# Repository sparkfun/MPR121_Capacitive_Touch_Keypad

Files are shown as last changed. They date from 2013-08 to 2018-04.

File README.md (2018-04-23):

**NOTE:** *This product has been retired from our catalog. If you are looking for more up-to-date info, please check out some of these resources to see how other users are still hacking and improving on this product.*
* *[SparkFun Forum](https://forum.sparkfun.com/)*
* *[Comments Here on GitHub](https://github.com/sparkfun/MPR121_Capacitive_Touch_Keypad/issues)*
* *[IRC Channel](https://www.sparkfun.com/news/263)*

MPR121 Capacitive Touch Keypad
==============================

Capacitive Touch Keypad

[MPR121 Capacitive Touch Keypad (SEN-12017)](https://www.sparkfun.com/products/12017)

The MPR121 capacitive keypad uses the MPR121 and 12 touch sensitive pads to give you a simple 'keypad' with an I2C output. The board 
also has four mounting holes allowing it to be used as na input system in place of traditional buttons. 

Note: This is uses 3.3V logic. You will want to use a logic level converter with this for 5V systems. 

Repository Contents
-------------------
* **/Firmware** - Any firmware that the part ships with, 
* **/Hardware** - All Eagle design files (.brd, .sch)
* **/Production** - Test bed files and production panel files

Documentation
--------------
* **[Hookup Guide](https://learn.sparkfun.com/tutorials/mpr121-hookup-guide)** - Basic hookup guide for the MPR121.

Version History
---------------
* [SEN-10250](https://www.sparkfun.com/products/10250) Version 1.3

License Information
-------------------
The hardware is released under [Creative Commons Share-alike 3.0](http://creativecommons.org/licenses/by-sa/3.0/).  
All other code is open source so please feel free to do anything you want with it; you buy me a beer if you use this and we meet someday ([Beerware license](http://en.wikipedia.org/wiki/Beerware)).

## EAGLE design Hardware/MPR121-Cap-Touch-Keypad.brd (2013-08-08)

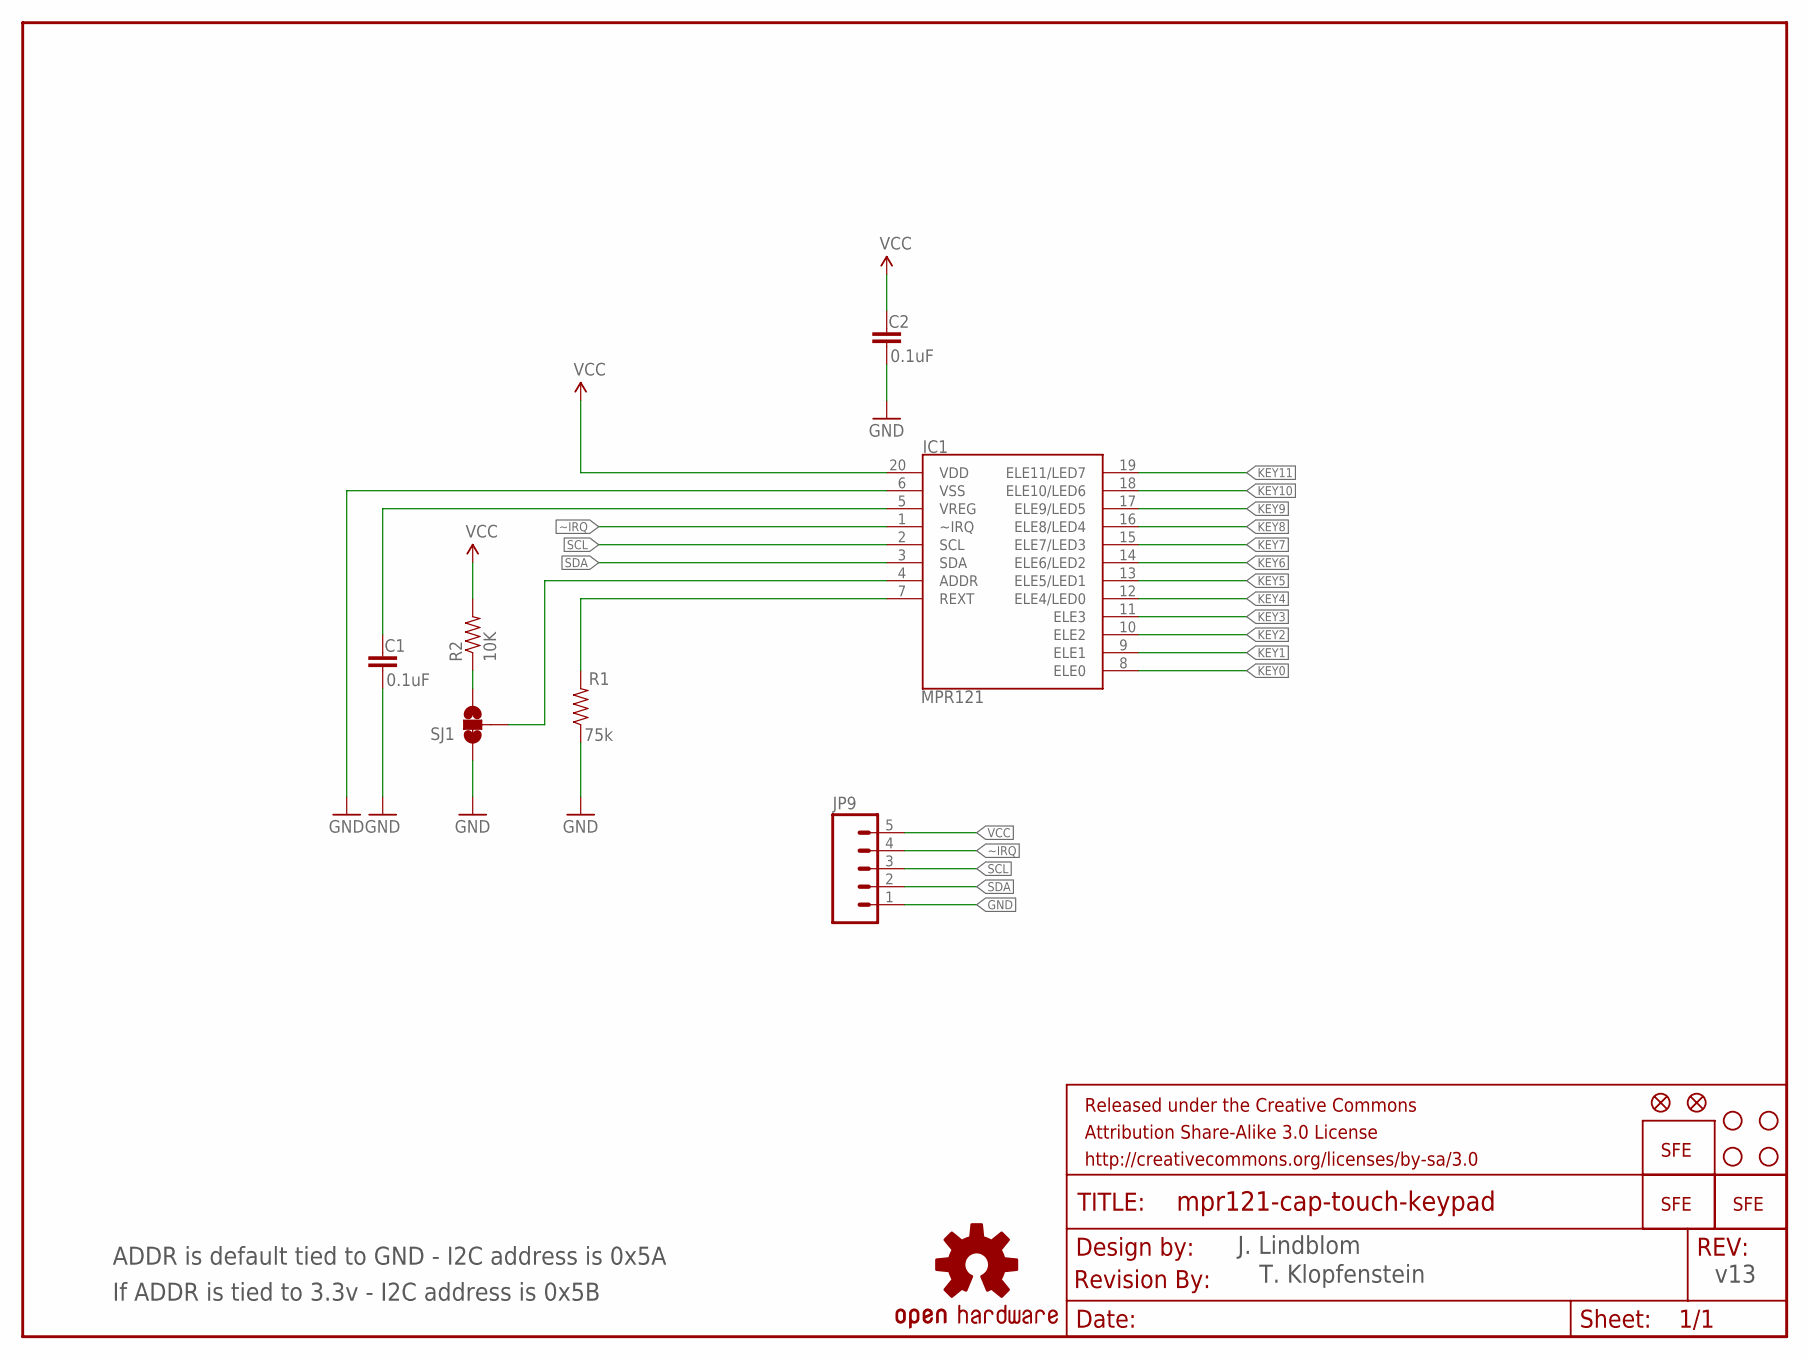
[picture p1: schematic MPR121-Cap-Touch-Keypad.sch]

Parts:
C1, C2: 0.1uF; 0603-CAP
FRAME1: FRAME-LETTER; CREATIVE_COMMONS
IC1: MPR121; QFN-20-0.4MM-V2
JP1: LOGO-SFENEW; SFE-NEW-WEBLOGO
JP2, JP6: LOGO-SFESK; SFE-LOGO-FLAME
JP3, JP4, JP7, JP8: STAND-OFF
JP5, JP10: FIDUCIAL1X2; FIDUCIAL-1X2
JP9: M05PTH; 1X05
LOGO1: OSHW-LOGOL; OSHW-LOGO-L
R1: 75k; 0603-RES
R2: 10K; 0603-RES
SJ1: SOLDERJUMPER_2WAYPASTE1&2; SJ_3_PASTE1&2
U$1: REVISION

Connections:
GND: C1.2, C2.2, IC1.6 (VSS), JP9.1, R1.1, SJ1.1
KEY0: IC1.8 (ELE0)
KEY1: IC1.9 (ELE1)
KEY2: IC1.10 (ELE2)
KEY3: IC1.11 (ELE3)
KEY4: IC1.12 (ELE4/LED0)
KEY5: IC1.13 (ELE5/LED1)
KEY6: IC1.14 (ELE6/LED2)
KEY7: IC1.15 (ELE7/LED3)
KEY8: IC1.16 (ELE8/LED4)
KEY9: IC1.17 (ELE9/LED5)
KEY10: IC1.18 (ELE10/LED6)
KEY11: IC1.19 (ELE11/LED7)
unnamed: IC1.4 (ADDR), SJ1.2
unnamed: R2.1, SJ1.3
REXT: IC1.7 (REXT), R1.2
SCL: IC1.2 (SCL), JP9.3
SDA: IC1.3 (SDA), JP9.2
VCC: C2.1, IC1.20 (VDD), JP9.5, R2.2
VREG: C1.1, IC1.5 (VREG)
~IRQ: IC1.1 (~IRQ), JP9.4

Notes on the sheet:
ADDR is default tied to GND - I2C address is 0x5A
v13
J. Lindblom
T. Klopfenstein
If ADDR is tied to 3.3v - I2C address is 0x5B

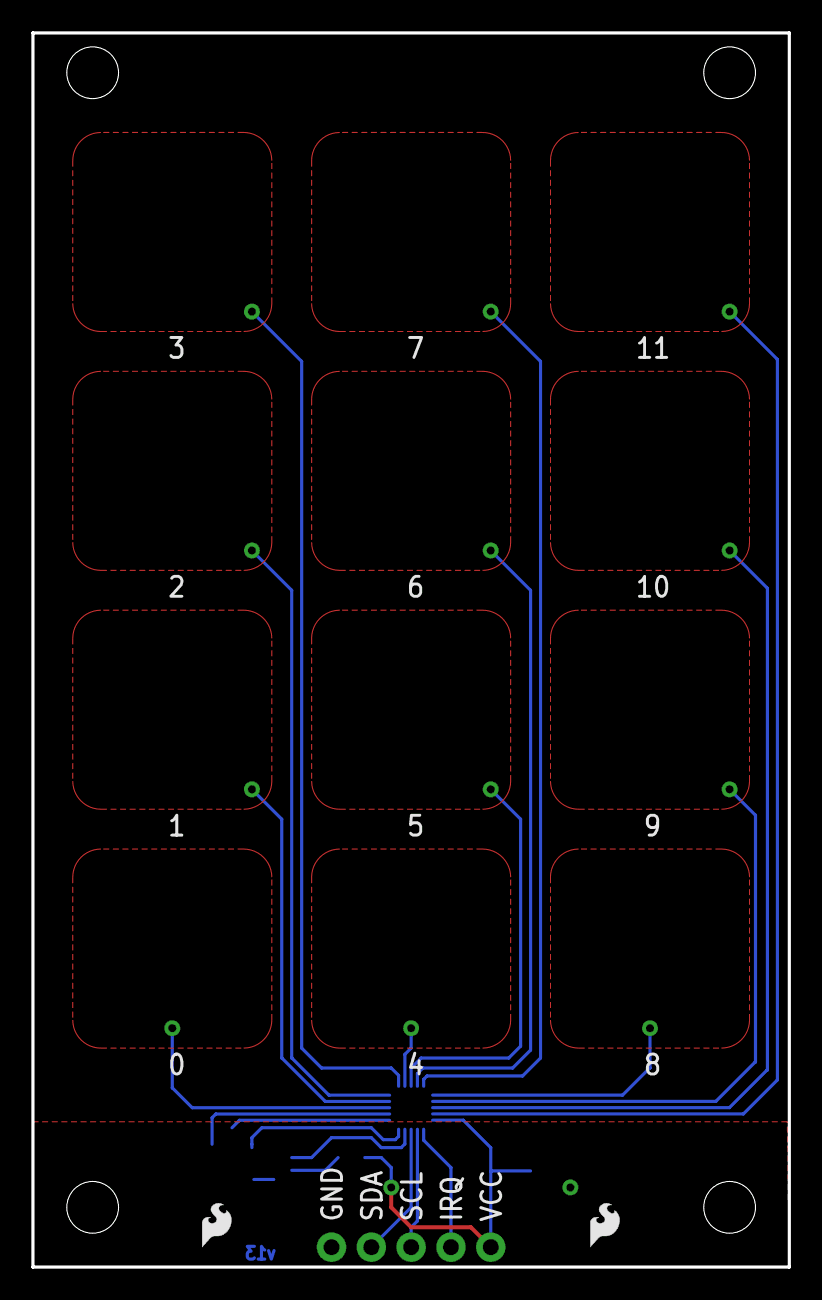
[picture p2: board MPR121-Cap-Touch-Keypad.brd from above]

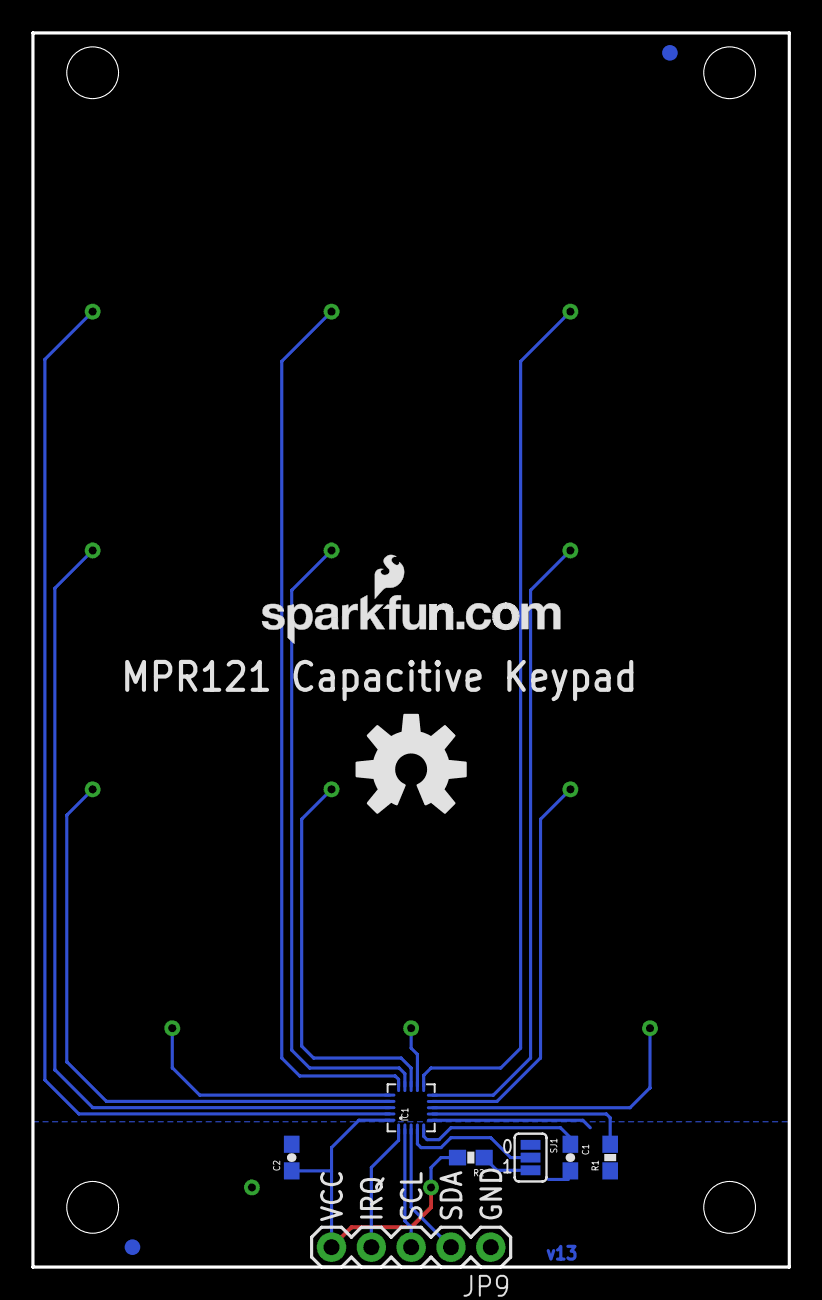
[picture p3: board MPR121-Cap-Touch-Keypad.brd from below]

Board: 2 copper layers, 48.3 x 78.7 mm, 19 parts (15 on the bottom side), 9 nets.

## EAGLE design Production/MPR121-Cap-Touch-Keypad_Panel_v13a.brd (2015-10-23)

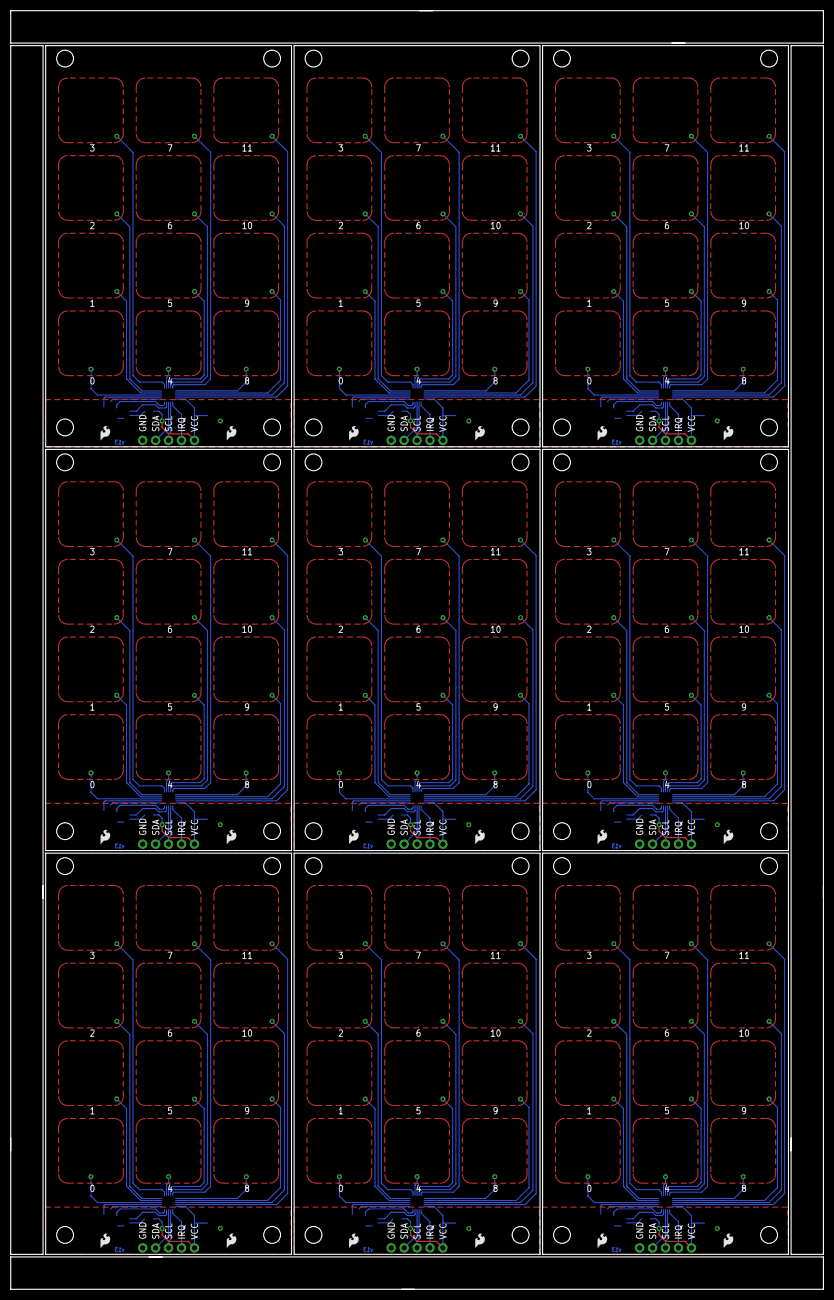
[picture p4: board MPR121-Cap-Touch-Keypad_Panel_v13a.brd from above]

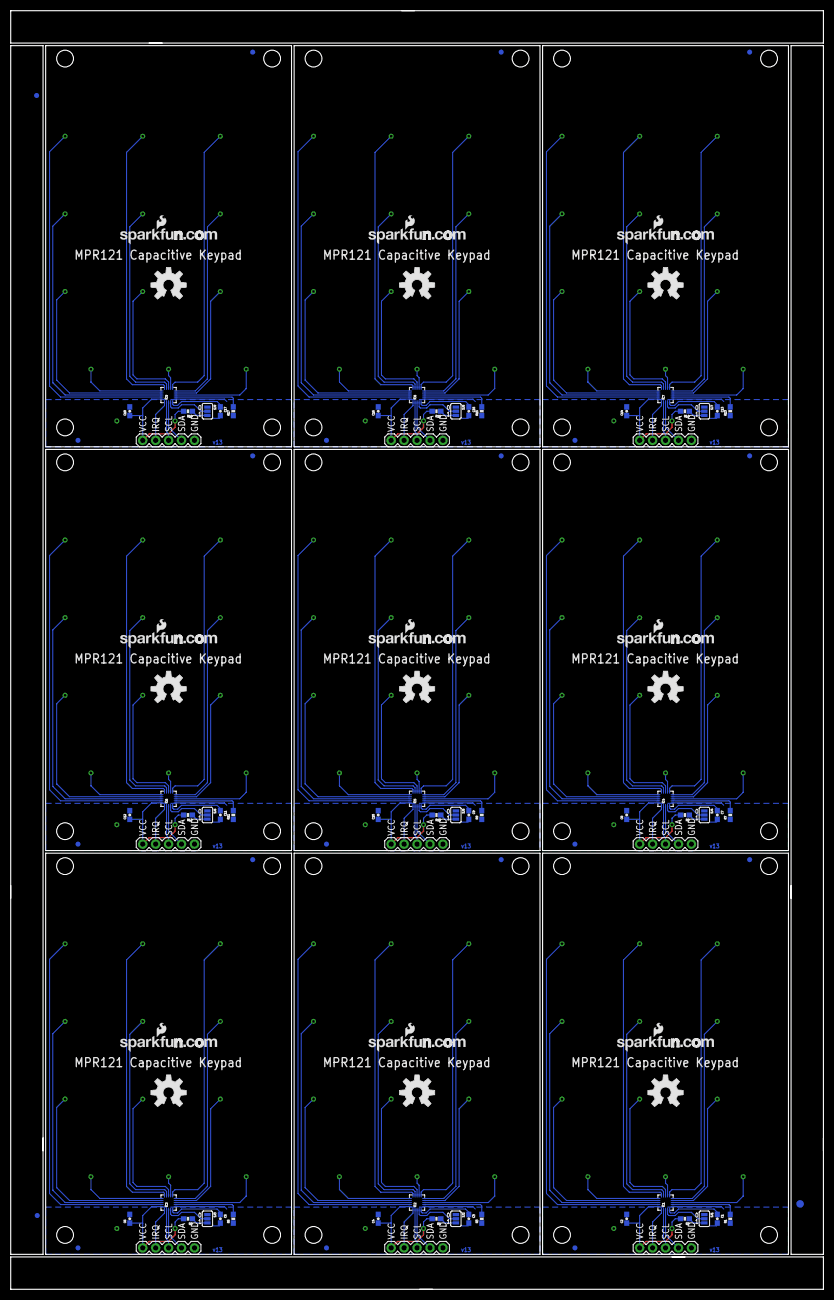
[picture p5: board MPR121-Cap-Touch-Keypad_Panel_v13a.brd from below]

Board: 2 copper layers, 159.5 x 251.0 mm, 156 parts (138 on the bottom side), 81 nets.

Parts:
C1, C2, C3, C4, C5, C6, C7, C8, C9, C10, C11, C12, C13, C14, C15, C16, C17, C18: 0.1uF; 0603-CAP
E$1, E$7: FIDUCIAL-1X2
E$2: FIDUCIAL-1.5X3
IC1, IC2, IC3, IC4, IC5, IC6, IC7, IC8, IC9: MPR121; QFN-20-0.4MM-V2
JP1, JP11, JP21, JP31, JP41, JP51, JP61, JP71, JP81: LOGO-SFENEW; SFE-NEW-WEBLOGO
JP2, JP6, JP14, JP15, JP24, JP25, JP34, JP35, JP44, JP45, JP54, JP55, JP64, JP65, JP74, JP75, JP84, JP85: LOGO-SFESK; SFE-LOGO-FLAME
JP3, JP4, JP7, JP8, JP12, JP13, JP16, JP17, JP22, JP23, JP26, JP27, JP32, JP33, JP36, JP37, JP42, JP43, JP46, JP47, JP52, JP53, JP56, JP57, JP62, JP63, JP66, JP67, JP72, JP73, JP76, JP77, JP82, JP83, JP86, JP87: STAND-OFF
JP5, JP10, JP19, JP20, JP29, JP30, JP39, JP40, JP49, JP50, JP59, JP60, JP69, JP70, JP79, JP80, JP89, JP90: FIDUCIAL1X2; FIDUCIAL-1X2
JP9, JP18, JP28, JP38, JP48, JP58, JP68, JP78, JP88: 1X05
LOGO1, LOGO2, LOGO3, LOGO4, LOGO5, LOGO6, LOGO7, LOGO8, LOGO9: OSHW-LOGOL; OSHW-LOGO-L
R1, R3, R5, R7, R9, R11, R13, R15, R17: 75k; 0603-RES
R2, R4, R6, R8, R10, R12, R14, R16, R18: 10K; 0603-RES
SJ1, SJ2, SJ3, SJ4, SJ5, SJ6, SJ7, SJ8, SJ9: SJ_3_PASTE1&2

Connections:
GND: C1.2, C2.2, IC1.6, JP9.1, R1.1, SJ1.1
GND1: C3.2, C4.2, IC2.6, JP18.1, R3.1, SJ2.1
GND2: C5.2, C6.2, IC3.6, JP28.1, R5.1, SJ3.1
GND3: C7.2, C8.2, IC4.6, JP38.1, R7.1, SJ4.1
GND4: C9.2, C10.2, IC5.6, JP48.1, R9.1, SJ5.1
GND5: C11.2, C12.2, IC6.6, JP58.1, R11.1, SJ6.1
GND6: C13.2, C14.2, IC7.6, JP68.1, R13.1, SJ7.1
GND7: C15.2, C16.2, IC8.6, JP78.1, R15.1, SJ8.1
GND8: C17.2, C18.2, IC9.6, JP88.1, R17.1, SJ9.1
unnamed: IC1.4, SJ1.2
unnamed: R2.1, SJ1.3
unnamed: IC2.4, SJ2.2
unnamed: R4.1, SJ2.3
unnamed: IC3.4, SJ3.2
unnamed: R6.1, SJ3.3
unnamed: IC4.4, SJ4.2
unnamed: R8.1, SJ4.3
unnamed: IC5.4, SJ5.2
unnamed: R10.1, SJ5.3
unnamed: IC6.4, SJ6.2
unnamed: R12.1, SJ6.3
unnamed: IC7.4, SJ7.2
unnamed: R14.1, SJ7.3
unnamed: IC8.4, SJ8.2
unnamed: R16.1, SJ8.3
unnamed: IC9.4, SJ9.2
unnamed: R18.1, SJ9.3
REXT: IC1.7, R1.2
REXT1: IC2.7, R3.2
REXT2: IC3.7, R5.2
REXT3: IC4.7, R7.2
REXT4: IC5.7, R9.2
REXT5: IC6.7, R11.2
REXT6: IC7.7, R13.2
REXT7: IC8.7, R15.2
REXT8: IC9.7, R17.2
SCL: IC1.2, JP9.3
SCL1: IC2.2, JP18.3
SCL2: IC3.2, JP28.3
SCL3: IC4.2, JP38.3
SCL4: IC5.2, JP48.3
SCL5: IC6.2, JP58.3
SCL6: IC7.2, JP68.3
SCL7: IC8.2, JP78.3
SCL8: IC9.2, JP88.3
SDA: IC1.3, JP9.2
SDA1: IC2.3, JP18.2
SDA2: IC3.3, JP28.2
SDA3: IC4.3, JP38.2
SDA4: IC5.3, JP48.2
SDA5: IC6.3, JP58.2
SDA6: IC7.3, JP68.2
SDA7: IC8.3, JP78.2
SDA8: IC9.3, JP88.2
VCC: C2.1, IC1.20, JP9.5, R2.2
VCC1: C4.1, IC2.20, JP18.5, R4.2
VCC2: C6.1, IC3.20, JP28.5, R6.2
VCC3: C8.1, IC4.20, JP38.5, R8.2
VCC4: C10.1, IC5.20, JP48.5, R10.2
VCC5: C12.1, IC6.20, JP58.5, R12.2
VCC6: C14.1, IC7.20, JP68.5, R14.2
VCC7: C16.1, IC8.20, JP78.5, R16.2
VCC8: C18.1, IC9.20, JP88.5, R18.2
VREG: C1.1, IC1.5
VREG1: C3.1, IC2.5
VREG2: C5.1, IC3.5
VREG3: C7.1, IC4.5
VREG4: C9.1, IC5.5
VREG5: C11.1, IC6.5
VREG6: C13.1, IC7.5
VREG7: C15.1, IC8.5
VREG8: C17.1, IC9.5
~IRQ: IC1.1, JP9.4
~IRQ1: IC2.1, JP18.4
~IRQ2: IC3.1, JP28.4
~IRQ3: IC4.1, JP38.4
~IRQ4: IC5.1, JP48.4
~IRQ5: IC6.1, JP58.4
~IRQ6: IC7.1, JP68.4
~IRQ7: IC8.1, JP78.4
~IRQ8: IC9.1, JP88.4

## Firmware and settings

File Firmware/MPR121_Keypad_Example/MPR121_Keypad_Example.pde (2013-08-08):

/* MPR121 Keypad Example Phone Dialing Code
 by: Jim Lindblom
     SparkFun Electronics
 created on: 1/6/10
 license: CC-SA 3.0
 
 Turns the MPR121 Touchpad into a phone keypad. Pressing a pad will
 print a 0-9, * or #.
 
 Hardware: 3.3V Arduino Pro Mini
           SDA -> A4
           SCL -> A5
           IRQ -> D2
           
 I wasn't having any luck using the Wire.h library, so I've adapted
 I2C code from an ATmega328 library to get this working.
 If you can get this working with the Wire.h library, I'd be thrilled to hear!
*/

#include "mpr121.h"
#include "i2c.h"

#define MPR121_R 0xB5	// ADD pin is grounded
#define MPR121_W 0xB4	// So address is 0x5A

#define PHONE_DIGITS 10  // 10 digits in a phone number

// Match key inputs with electrode numbers
#define STAR 0
#define SEVEN 1
#define FOUR 2
#define ONE 3
#define ZERO 4
#define EIGHT 5
#define FIVE 6
#define TWO 7
#define POUND 8
#define NINE 9
#define SIX 10
#define THREE 11

int irqpin = 2;  // D2

uint16_t touchstatus;
char phoneNumber[PHONE_DIGITS];

void setup()
{
  pinMode(irqpin, INPUT);
  digitalWrite(irqpin, HIGH);
  
  Serial.begin(9600);
  DDRC |= 0b00010011;
  PORTC = 0b00110000;  // Pull-ups on I2C Bus
  i2cInit();
  
  delay(100);
  mpr121QuickConfig();
}

void loop()
{
  getPhoneNumber();
  
  Serial.print("\nDialing... ");
  for (int i=0; i<PHONE_DIGITS; i++)
    Serial.print(phoneNumber[i]);
  
  while(1)
    ;
}

void getPhoneNumber()
{
  int i = 0;
  int touchNumber;
  
  Serial.println("Please Enter a phone number...");
  
  while(i<PHONE_DIGITS)
  {
    while(checkInterrupt())
      ;
    touchNumber = 0;
    
    touchstatus = mpr121Read(0x01) << 8;
    touchstatus |= mpr121Read(0x00);
    
    for (int j=0; j<12; j++)  // Check how many electrodes were pressed
    {
      if ((touchstatus & (1<<j)))
        touchNumber++;
    }
    
    if (touchNumber == 1)
    {
      if (touchstatus & (1<<STAR))
        phoneNumber[i] = '*';
      else if (touchstatus & (1<<SEVEN))
        phoneNumber[i] = '7';
      else if (touchstatus & (1<<FOUR))
        phoneNumber[i] = '4';
      else if (touchstatus & (1<<ONE))
        phoneNumber[i] = '1';
      else if (touchstatus & (1<<ZERO))
        phoneNumber[i] = '0';
      else if (touchstatus & (1<<EIGHT))
        phoneNumber[i] = '8';
      else if (touchstatus & (1<<FIVE))
        phoneNumber[i] = '5';
      else if (touchstatus & (1<<TWO))
        phoneNumber[i] = '2';
      else if (touchstatus & (1<<POUND))
        phoneNumber[i] = '#';
      else if (touchstatus & (1<<NINE))
        phoneNumber[i] = '9';
      else if (touchstatus & (1<<SIX))
        phoneNumber[i] = '6';
      else if (touchstatus & (1<<THREE))
        phoneNumber[i] = '3';
        
      Serial.print(phoneNumber[i]);
      i++;
    }
    else if (touchNumber == 0)
      ;
    else
      Serial.println("Only touch ONE button!");
  }
}

byte mpr121Read(uint8_t address)
{
  byte data;
  
  i2cSendStart();
  i2cWaitForComplete();
  
  i2cSendByte(MPR121_W);	// write 0xB4
  i2cWaitForComplete();
  
  i2cSendByte(address);	// write register address
  i2cWaitForComplete();
  
  i2cSendStart();
  
  i2cSendByte(MPR121_R);	// write 0xB5
  i2cWaitForComplete();
  i2cReceiveByte(TRUE);
  i2cWaitForComplete();
  
  data = i2cGetReceivedByte();	// Get MSB result
  i2cWaitForComplete();
  i2cSendStop();
  
  cbi(TWCR, TWEN);	// Disable TWI
  sbi(TWCR, TWEN);	// Enable TWI
  
  return data;
}

void mpr121Write(unsigned char address, unsigned char data)
{
  i2cSendStart();
  i2cWaitForComplete();
  
  i2cSendByte(MPR121_W);// write 0xB4
  i2cWaitForComplete();
  
  i2cSendByte(address);	// write register address
  i2cWaitForComplete();
  
  i2cSendByte(data);
  i2cWaitForComplete();
  
  i2cSendStop();
}

void mpr121QuickConfig(void)
{
  // Section A
  // This group controls filtering when data is > baseline.
  mpr121Write(MHD_R, 0x01);
  mpr121Write(NHD_R, 0x01);
  mpr121Write(NCL_R, 0x00);
  mpr121Write(FDL_R, 0x00);

  // Section B
  // This group controls filtering when data is < baseline.
  mpr121Write(MHD_F, 0x01);
  mpr121Write(NHD_F, 0x01);
  mpr121Write(NCL_F, 0xFF);
  mpr121Write(FDL_F, 0x02);
  
  // Section C
  // This group sets touch and release thresholds for each electrode
  mpr121Write(ELE0_T, TOU_THRESH);
  mpr121Write(ELE0_R, REL_THRESH);
  mpr121Write(ELE1_T, TOU_THRESH);
  mpr121Write(ELE1_R, REL_THRESH);
  mpr121Write(ELE2_T, TOU_THRESH);
  mpr121Write(ELE2_R, REL_THRESH);
  mpr121Write(ELE3_T, TOU_THRESH);
  mpr121Write(ELE3_R, REL_THRESH);
  mpr121Write(ELE4_T, TOU_THRESH);
  mpr121Write(ELE4_R, REL_THRESH);
  mpr121Write(ELE5_T, TOU_THRESH);
  mpr121Write(ELE5_R, REL_THRESH);
  mpr121Write(ELE6_T, TOU_THRESH);
  mpr121Write(ELE6_R, REL_THRESH);
  mpr121Write(ELE7_T, TOU_THRESH);
  mpr121Write(ELE7_R, REL_THRESH);
  mpr121Write(ELE8_T, TOU_THRESH);
  mpr121Write(ELE8_R, REL_THRESH);
  mpr121Write(ELE9_T, TOU_THRESH);
  mpr121Write(ELE9_R, REL_THRESH);
  mpr121Write(ELE10_T, TOU_THRESH);
  mpr121Write(ELE10_R, REL_THRESH);
  mpr121Write(ELE11_T, TOU_THRESH);
  mpr121Write(ELE11_R, REL_THRESH);
  
  // Section D
  // Set the Filter Configuration
  // Set ESI2
  mpr121Write(FIL_CFG, 0x04);
  
  // Section E
  // Electrode Configuration
  // Enable 6 Electrodes and set to run mode
  // Set ELE_CFG to 0x00 to return to standby mode
  mpr121Write(ELE_CFG, 0x0C);	// Enables all 12 Electrodes
  //mpr121Write(ELE_CFG, 0x06);		// Enable first 6 electrodes
  
  // Section F
  // Enable Auto Config and auto Reconfig
  /*mpr121Write(ATO_CFG0, 0x0B);
  mpr121Write(ATO_CFGU, 0xC9);	// USL = (Vdd-0.7)/vdd*256 = 0xC9 @3.3V   mpr121Write(ATO_CFGL, 0x82);	// LSL = 0.65*USL = 0x82 @3.3V
  mpr121Write(ATO_CFGT, 0xB5);*/	// Target = 0.9*USL = 0xB5 @3.3V
}

byte checkInterrupt(void)
{
  if(digitalRead(irqpin))
    return 1;

  return 0;
}

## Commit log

2013-08-08 Adding firmware, updated board files, and gitignore
    [MPR121-Cap-Touch-Keypad.brd, MPR121-Cap-Touch-Keypad.sch]
2013-08-08 Changing packages to Production IDs on caps/res
    [MPR121-Cap-Touch-Keypad.brd, MPR121-Cap-Touch-Keypad.sch]
2013-10-02 Created Panel
    v13 panel
    [MPR121-Cap-Touch-Keypad-Panel-v13.brd]
2015-10-16 created new v13 panel
    [MPR121-Cap-Touch-Keypad-Panel-v13.brd, MPR121-Cap-Touch-Keypad_Panel_v13a.brd]
2015-10-23 moved fids to the bottom
    [MPR121-Cap-Touch-Keypad_Panel_v13a.brd]

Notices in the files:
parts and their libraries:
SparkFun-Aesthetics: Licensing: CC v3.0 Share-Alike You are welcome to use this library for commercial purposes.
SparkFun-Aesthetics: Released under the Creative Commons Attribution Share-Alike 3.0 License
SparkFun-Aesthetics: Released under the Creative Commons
